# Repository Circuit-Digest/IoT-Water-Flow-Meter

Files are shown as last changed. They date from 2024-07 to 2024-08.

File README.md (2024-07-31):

# DIY ESP32-Based Water Flow Meter: Conserve Water, Save the Planet
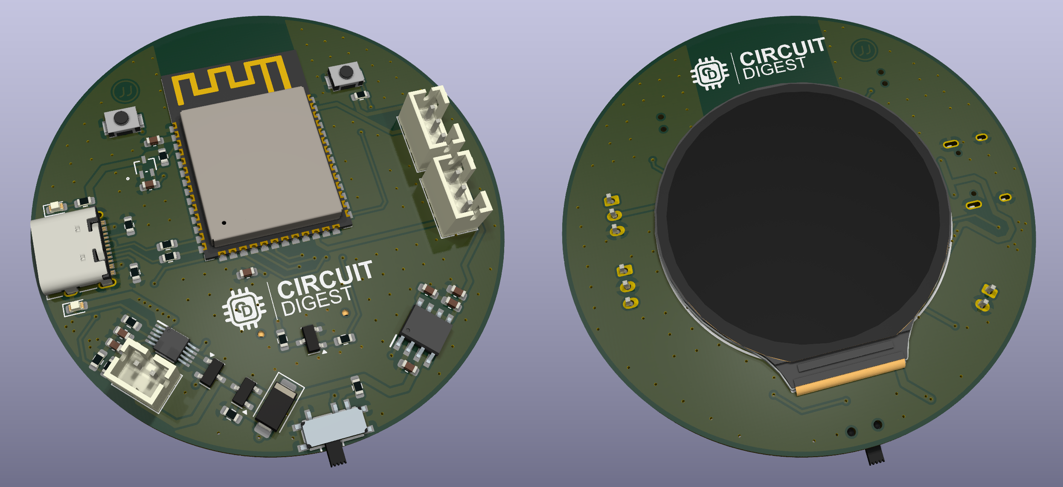
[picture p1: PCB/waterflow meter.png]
Water Flow Meter Water Flow Meter PCB

Water is one of our most precious resources, vital for all forms of life on Earth. Despite its importance, water wastage is a significant issue globally, contributing to water scarcity and environmental degradation. Efficient water management is crucial in addressing this challenge, and technology plays a vital role in it. By monitoring and managing water usage, we can significantly reduce wastage. As a first step in addressing this, we have designed an IoT based water flow meter. It is powered by the ESP32-S3 SoC from Espressif. We have used an ESP32-S3 Wroom 1 module for the project which will be much easier to handle when assembling the PCB. the device itself is battery powered and the custom PCB contains the necessary battery charging circuitry to recharge the internal battery. The battery charging circuit is based on the MAX1898 single-cell battery charger chip from Analog Devices. For powering the ESP32-S3 we have used the ADP1706 ultra low noise LDO, and for the reset circuitry we have used the ADM803 power supervisory chip. We have also included a provision for a 1.28” round TFT display for any future upgrades. The flow meter can be directly attached to the top of the flow sensor.

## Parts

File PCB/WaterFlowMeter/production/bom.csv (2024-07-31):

Designator | Footprint | Quantity | Value | LCSC Part #
BOOT1 | Tactile 3x4x2mm TS-A010 | 1 | UBOOT
BOOT2 | Tactile 3x4x2mm TS-A010 | 1 | RESET
C1, C2, C7 | 0603 | 3 | 0.1uF
C3, C5, C8, C9 | 0603 | 4 | 10uF
C4, C6 | 0603 | 2 | 1uF
D2 | D_SMA | 1 | SS14D
IC2 | SOIC127P600X175-9N | 1 | ADP1706ARDZ-3.3-R7
IC3 | SOP50P490X110-10N | 1 | MAX1898EUB42+T
J1 | USB_C_Receptacle_XKB_U262-16XN-4BVC11 | 1 | USB_C_Receptacle_USB2.0
J2, J4 | JST_PH_B3B-PH-K_1x03_P2.00mm_Vertical | 2 | Conn_01x03
J3 | JST_PH_B2B-PH-K_1x02_P2.00mm_Vertical | 1 | B2B-PH-SM4-TB(LF)(SN)
J5 | GC9A01 | 1 | GC9A01
LED1 | 0603 | 1 | LED Red
LED4 | 0603 | 1 | LED Blue
Q1 | SOT-23 | 1 | S8050
R1, R3, R4 | 0603 | 3 | 10K
R10, R11, R13, R14 | 0603 | 4 | 100K
R12 | 0603 | 1 | 1.4K
R2 | 0603 | 1 | 10
R5, R6 | 0603 | 2 | 33R
R7, R8 | 0603 | 2 | 5K1
R9 | 0603 | 1 | 1K
SW1 | slide switch spdt | 1 | SLW-66527511-SMT-TR
U1, U5 | SOT-23 | 2 | AO3401A
U2 | ESP32-S3-WROOM-1 | 1 | ESP32-S3-WROOM-1
U8 | KS_3_ADI | 1 | ADM803SAKSZ-REEL7

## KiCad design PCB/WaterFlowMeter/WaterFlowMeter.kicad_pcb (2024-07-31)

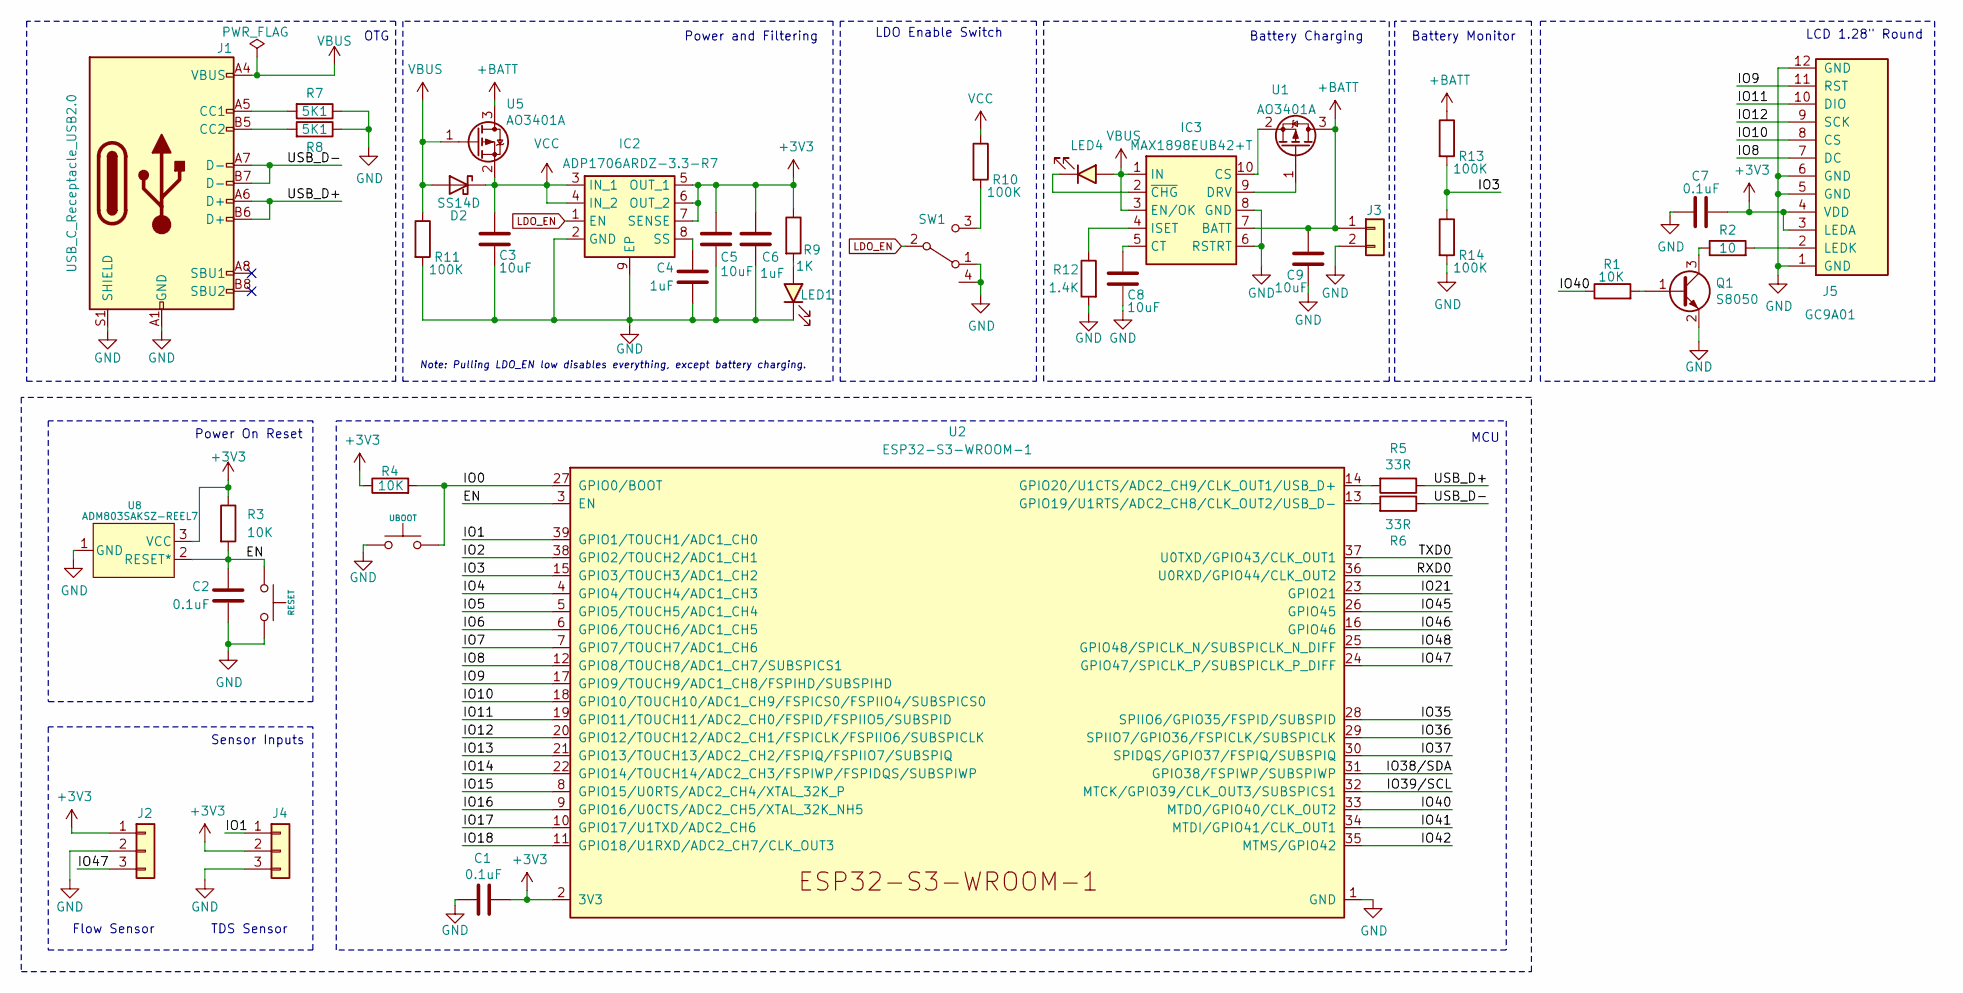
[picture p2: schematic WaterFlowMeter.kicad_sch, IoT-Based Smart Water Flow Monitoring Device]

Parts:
BOOT1: UBOOT; Tactile 3x4x2mm TS-A010; DigiKey Part Number 2449-CS1213AGF160CT-ND
BOOT2: RESET; Tactile 3x4x2mm TS-A010; DigiKey Part Number 2449-CS1213AGF160CT-ND
C1, C2, C7: 0.1uF; C_0603_1608Metric; DigiKey Part Number 490-6328-1-ND
C3, C5, C8, C9: 10uF; C_0603_1608Metric; DigiKey Part Number 490-10692-1-ND
C4, C6: 1uF; C_0603_1608Metric; DigiKey Part Number 490-10018-1-ND
D2: SS14D; D_SMA; DigiKey Part Number SS14CT-ND
IC2: ADP1706ARDZ-3.3-R7; SOIC127P600X175-9N; DigiKey Part Number 505-ADP1706ARDZ-3.3-R7CT-ND
IC3: MAX1898EUB42+T; SOP50P490X110-10N; DigiKey Part Number MAX1898EUB42+TCT-ND
J1: USB_C_Receptacle_USB2.0; USB_C_Receptacle_XKB_U262-16XN-4BVC11; DigiKey Part Number 664-12402012E212ACT-ND
J2, J4: Conn_01x03; JST_PH_B3B-PH-K_1x03_P2.00mm_Vertical; DigiKey Part Number A100035-ND
J3: B2B-PH-SM4-TB(LF)(SN); JST_PH_B2B-PH-K_1x02_P2.00mm_Vertical; DigiKey Part Number 455-1704-ND
J5: GC9A01
LED1: LED Red; LED_0603_1608Metric; DigiKey Part Number 3147-B1911USD-20D000114U1930CT-ND
LED4: LED Blue; LED_0603_1608Metric; DigiKey Part Number 3147-B1911NB--20C005314U1930CT-ND
Q1: S8050; SOT-23; DigiKey Part Number MMSS8050-L-TPMSCT-ND
R1, R3, R4: 10K; R_0603_1608Metric; DigiKey Part Number P10.0KHCT-ND
R2: 10; R_0603_1608Metric; DigiKey Part Number P10.0HCT-ND
R5, R6: 33R; R_0603_1608Metric; DigiKey Part Number P17467CT-ND
R7, R8: 5K1; R_0603_1608Metric; DigiKey Part Number P5.10KHCT-ND
R9: 1K; R_0603_1608Metric; DigiKey Part Number P1.00KHCT-ND
R10, R11, R13, R14: 100K; R_0603_1608Metric; DigiKey Part Number P100KHCT-ND
R12: 1.4K; R_0603_1608Metric; DigiKey Part Number P1.40KHCT-ND
SW1: SLW-66527511-SMT-TR; slide switch spdt; DigiKey Part Number 2223-SLW-66527511-SMT-TRCT-ND
U1, U5: AO3401A; SOT-23; DigiKey Part Number AO3401-ND
U2: ESP32-S3-WROOM-1; DigiKey Part Number 1965-ESP32-S3-WROOM-1-N16R8CT-ND
U8: ADM803SAKSZ-REEL7; KS_3_ADI; DigiKey Part Number 505-ADM803SAKSZ-REEL7CT-ND

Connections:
+BATT: C9.1, IC3.7 (BATT), J3.1, R13.1, U1.3 (D), U5.3 (D)
/EN: BOOT2.1, C2.1, R3.2, U2.3 (EN), U8.2 (RESET*)
/IO0: BOOT1.1, R4.2, U2.27 (GPIO0/BOOT)
/IO1: J4.1, U2.39 (GPIO1/TOUCH1/ADC1_CH0)
/IO2: U2.38 (GPIO2/TOUCH2/ADC1_CH1)
/IO3: R13.2, R14.1, U2.15 (GPIO3/TOUCH3/ADC1_CH2)
/IO4: U2.4 (GPIO4/TOUCH4/ADC1_CH3)
/IO5: U2.5 (GPIO5/TOUCH5/ADC1_CH4)
/IO6: U2.6 (GPIO6/TOUCH6/ADC1_CH5)
/IO7: U2.7 (GPIO7/TOUCH7/ADC1_CH6)
/IO8: J5.7 (DC), U2.12 (GPIO8/TOUCH8/ADC1_CH7/SUBSPICS1)
/IO9: J5.11 (RST), U2.17 (GPIO9/TOUCH9/ADC1_CH8/FSPIHD/SUBSPIHD)
/IO10: J5.8 (CS), U2.18 (GPIO10/TOUCH10/ADC1_CH9/FSPICS0/FSPIIO4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)
/IO11: J5.10 (DIO), U2.19 (GPIO11/TOUCH11/ADC2_CH0/FSPID/FSPIIO5/S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)
/IO12: J5.9 (SCK), U2.20 (GPIO12/TOUCH12/ADC2_CH1/FSPICLK/FSPIIO6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)
/IO13: U2.21 (GPIO13/TOUCH13/ADC2_CH2/FSPIQ/FSPIIO7/S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)
/IO14: U2.22 (GPIO14/TOUCH14/ADC2_CH3/FSPIWP/FSPIDQS/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)
/IO15: U2.8 (GPIO15/U0RTS/ADC2_CH4/XTAL_32K_P)
/IO16: U2.9 (GPIO16/U0CTS/ADC2_CH5/XTAL_32K_NH5)
/IO17: U2.10 (GPIO17/U1TXD/ADC2_CH6)
/IO18: U2.11 (GPIO18/U1RXD/ADC2_CH7/CLK_OUT3)
/IO21: U2.23 (GPIO21)
/IO35: U2.28 (SPIIO6/GPIO35/FSPID/SUBSPID)
/IO36: U2.29 (SPIIO7/GPIO36/FSPICLK/SUBSPICLK)
/IO37: U2.30 (SPIDQS/GPIO37/FSPIQ/SUBSPIQ)
/IO38/SDA: U2.31 (GPIO38/FSPIWP/SUBSPIWP)
/IO39/SCL: U2.32 (MTCK/GPIO39/CLK_OUT3/SUBSPICS1)
/IO40: R1.1, U2.33 (MTDO/GPIO40/CLK_OUT2)
/IO41: U2.34 (MTDI/GPIO41/CLK_OUT1)
/IO42: U2.35 (MTMS/GPIO42)
/IO45: U2.26 (GPIO45)
/IO46: U2.16 (GPIO46)
/IO47: J2.3, U2.24 (GPIO47/SPICLK_P/SUBSPICLK_P_DIFF)
/IO48: U2.25 (GPIO48/SPICLK_N/SUBSPICLK_N_DIFF)
/RXD0: U2.36 (U0RXD/GPIO44/CLK_OUT2)
/TXD0: U2.37 (U0TXD/GPIO43/CLK_OUT1)
/USB_D+: J1.A6 (D+), J1.B6 (D+), R5.1
/USB_D-: J1.A7 (D-), J1.B7 (D-), R6.1
LDO_EN: IC2.1 (EN), SW1.2 (B)
unnamed: C4.1, IC2.8 (SS)
unnamed: IC3.10 (CS), U1.2 (S)
unnamed: C8.1, IC3.5 (CT)
unnamed: IC3.9 (DRV), U1.1 (G)
unnamed: IC3.4 (ISET), R12.1
unnamed: IC3.2 (~CHG), LED4.1 (K)
unnamed: J1.A5 (CC1), R7.2
unnamed: J1.B5 (CC2), R8.2
unnamed: J5.2 (LEDK), R2.2
unnamed: LED1.2 (A), R9.2
unnamed: Q1.3 (C), R2.1
unnamed: Q1.1 (E), R1.2
unnamed: R10.2, SW1.3 (C)
unnamed: R6.2, U2.13 (GPIO19/U1RTS/ADC2_CH8/CLK_OUT2/USB_D-)
unnamed: R5.2, U2.14 (GPIO20/U1CTS/ADC2_CH9/CLK_OUT1/USB_D+)
VBUS: D2.2 (A), IC3.1 (IN), IC3.3 (EN/OK), J1.A4 (VBUS), J1.A9 (VBUS), J1.B4 (VBUS), J1.B9 (VBUS), LED4.2 (A), R11.1, U5.1 (G)
VCC: C3.1, D2.1 (K), IC2.3 (IN_1), IC2.4 (IN_2), R10.1, U5.2 (S)

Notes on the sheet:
OTG
TDS Sensor
Note: Pulling LDO_EN low disables everything, except battery charging.
Sensor Inputs
Power On Reset
Battery Charging
MCU
LCD 1.28" Round
LDO Enable Switch
Battery Monitor
Flow Sensor
Power and Filtering

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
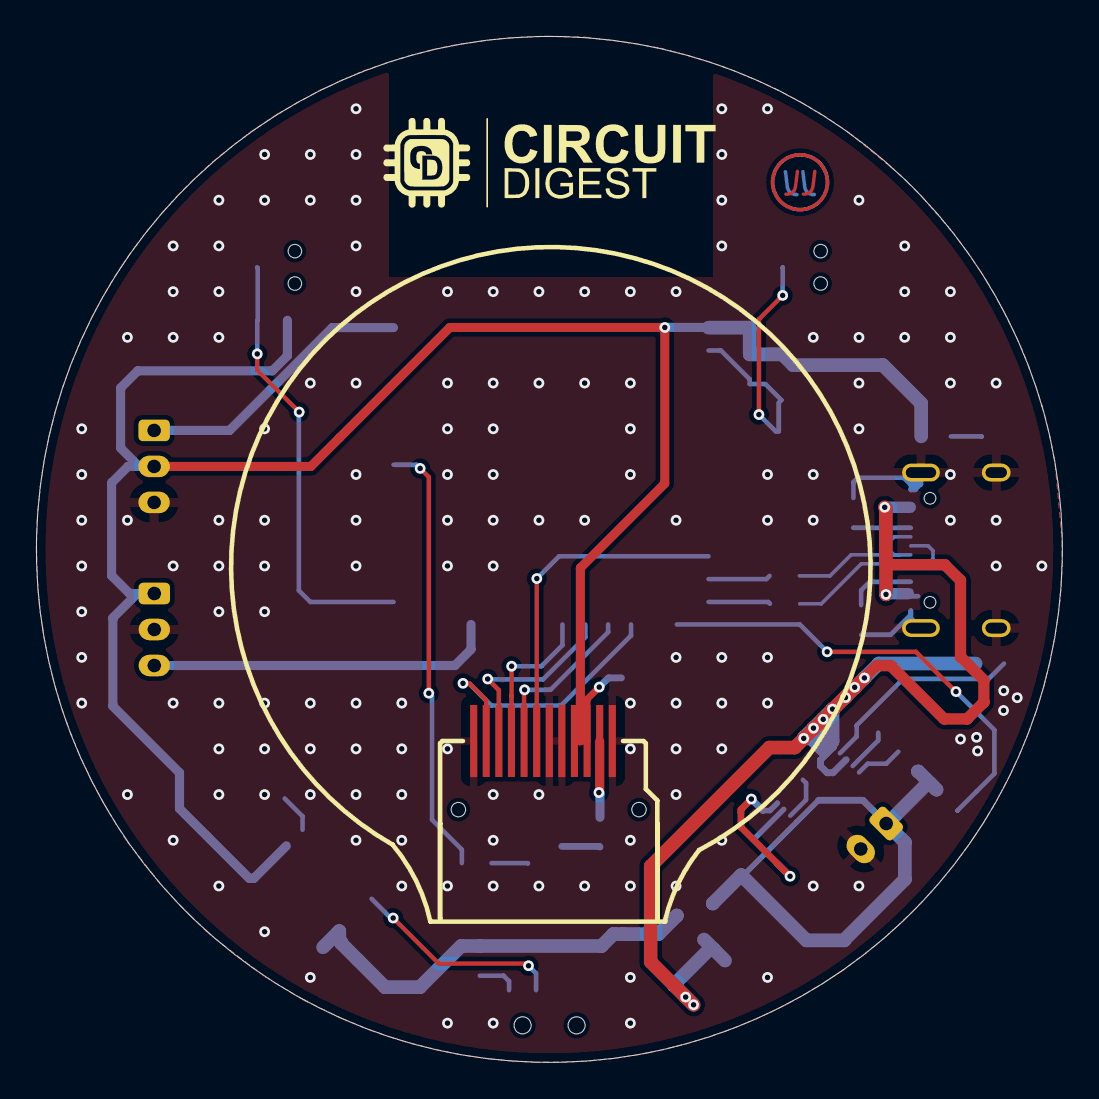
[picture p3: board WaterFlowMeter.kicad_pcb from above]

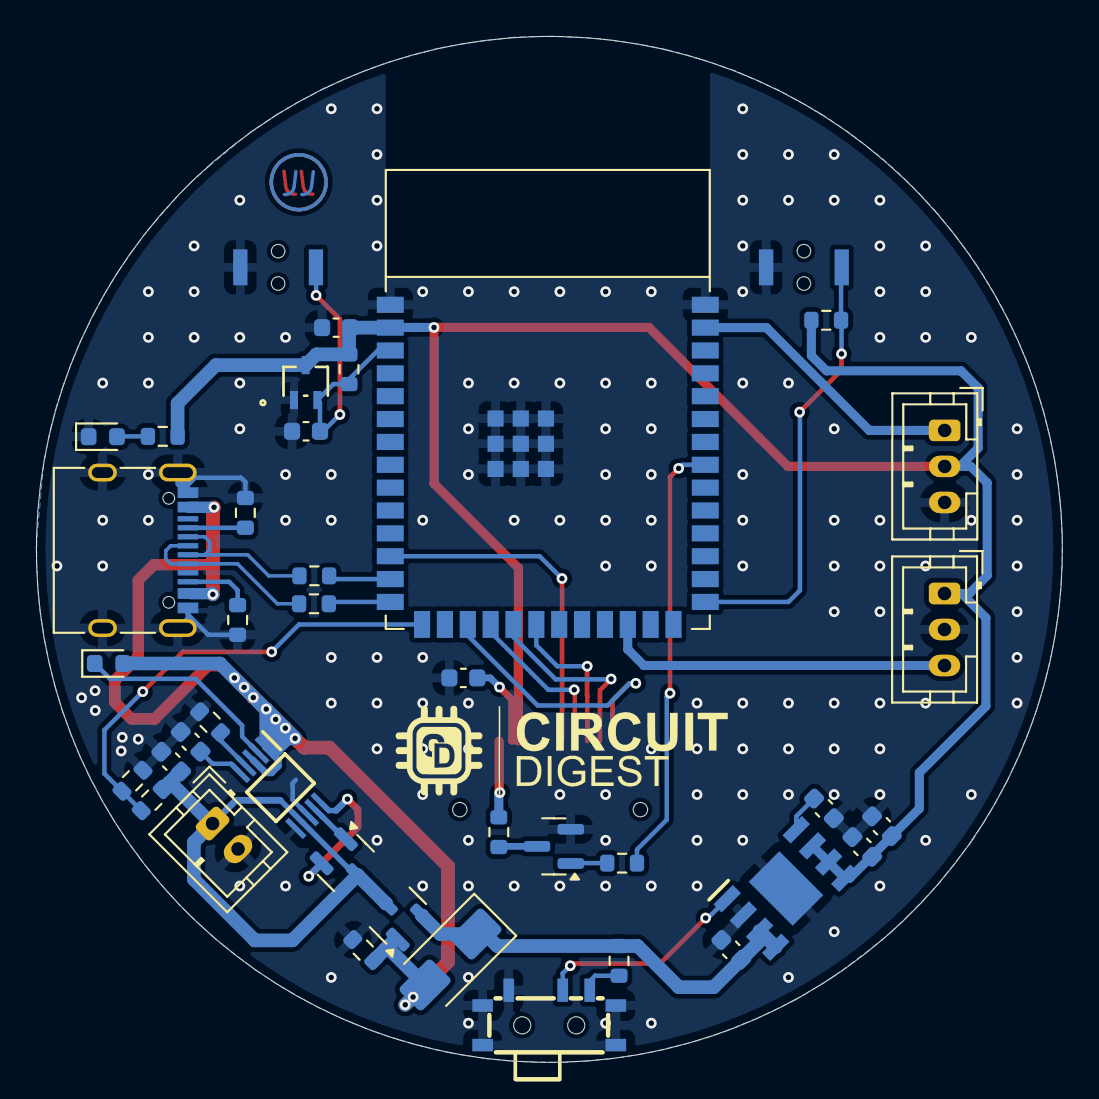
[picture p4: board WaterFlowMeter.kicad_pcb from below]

Board: 2 copper layers, 57.0 x 57.0 mm, 41 parts (40 on the bottom side), 34 nets.

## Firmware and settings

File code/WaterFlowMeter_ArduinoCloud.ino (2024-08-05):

/*
  This program measures the flow rate and total volume of liquid passing through a flow sensor,
  synchronizes the device's time with an NTP server, and updates these values to the Arduino IoT Cloud.
  The program features:
  - Measurement of flow rate in liters per minute.
  - Calculation of total volume in milliliters and liters.
  - Periodic updates of flow rate and total volume to the Arduino IoT Cloud.
  - A reset function to reset the total volume measurement.
*/


#include <WiFi.h>
#include "thingProperties.h"

#define SENSOR  47

long currentMillis = 0;
long previousMillis = 0;
int interval = 1000;
float calibrationFactor = 7.8;
volatile byte pulseCount;
byte pulse1Sec = 0;
float flowRate;
unsigned int flowMilliLitres;
float totalMilliLitres;

// Interrupt service routine for counting pulses from the flow sensor
void IRAM_ATTR pulseCounter() {
  pulseCount++;
}

void setup() {
  Serial.begin(115200);

  // Initialize IoT properties
  initProperties();

  // Connect to Arduino IoT Cloud
  ArduinoCloud.begin(ArduinoIoTPreferredConnection);

  // Set the debug message level
  setDebugMessageLevel(2);
  ArduinoCloud.printDebugInfo();

  // Initialize the flow sensor pin
  pinMode(SENSOR, INPUT_PULLUP);

  // Initialize flow measurement variables
  pulseCount = 0;
  flowRate = 0.0;
  flowMilliLitres = 0;
  totalMilliLitres = 0;
  previousMillis = 0;

  // Attach interrupt to the flow sensor pin
  attachInterrupt(digitalPinToInterrupt(SENSOR), pulseCounter, FALLING);

}

void loop() {
  ArduinoCloud.update();

  // Get current time in milliseconds
  currentMillis = millis();

  // If the interval has passed, calculate flow rate and total volume
  if (currentMillis - previousMillis > interval) {
    pulse1Sec = pulseCount;
    pulseCount = 0;

    // Calculate flow rate and update previousMillis
    flowRate = ((1000.0 / (millis() - previousMillis)) * pulse1Sec) / calibrationFactor;
    previousMillis = millis();

    // Calculate the flow volume in milliliters
    flowMilliLitres = (flowRate / 60) * 1000;
    totalMilliLitres += flowMilliLitres;

    // Print flow rate and total volume to the Serial Monitor
    Serial.print("Flow rate: ");
    Serial.print(int(flowRate));  // Print the integer part of the variable
    Serial.print(" L/min\t");

    Serial.print("Output Liquid Quantity: ");
    Serial.print(totalMilliLitres);
    Serial.print(" mL / ");
    Serial.print(totalMilliLitres / 1000);
    Serial.println(" L");

    // Update the cloud variables
    flowRateCloud = flowRate;
    totalLitersCloud = totalMilliLitres / 1000;
  }
}

// Function to reset total volume when the reset button is pressed
void onResetButtonCloudChange()  {
  if (resetButtonCloud) {
    totalLitersCloud = totalMilliLitres = 0;
  }
}
